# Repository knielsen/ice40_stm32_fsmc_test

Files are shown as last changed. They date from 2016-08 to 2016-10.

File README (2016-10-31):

Small test of fast communication between STM32F4 and ICE40 using the STM32 FSMC.

Pinout for the FSMC (this for plugged into the J3 slot):

  func  STM32  ICE40
  A0    PF0    R4
  A1    PF1    R3
  D0	PD14   N10
  D1	PD15   M11
  D2	PD0    T16
  NE2	PG9    N12
  NOE	PD4    T13
  NWE	PD5    P13

The external clock for the ICE40 is on J3. A test pin PB11 on the
STM32F4 is connected to R16 on the ICE40. A serial Tx out from STM32
can be connected from PB10 on the STM32F4 board to T15 on the ICE40
(will be proxied to the FTDI on the ICE40 breakout board).

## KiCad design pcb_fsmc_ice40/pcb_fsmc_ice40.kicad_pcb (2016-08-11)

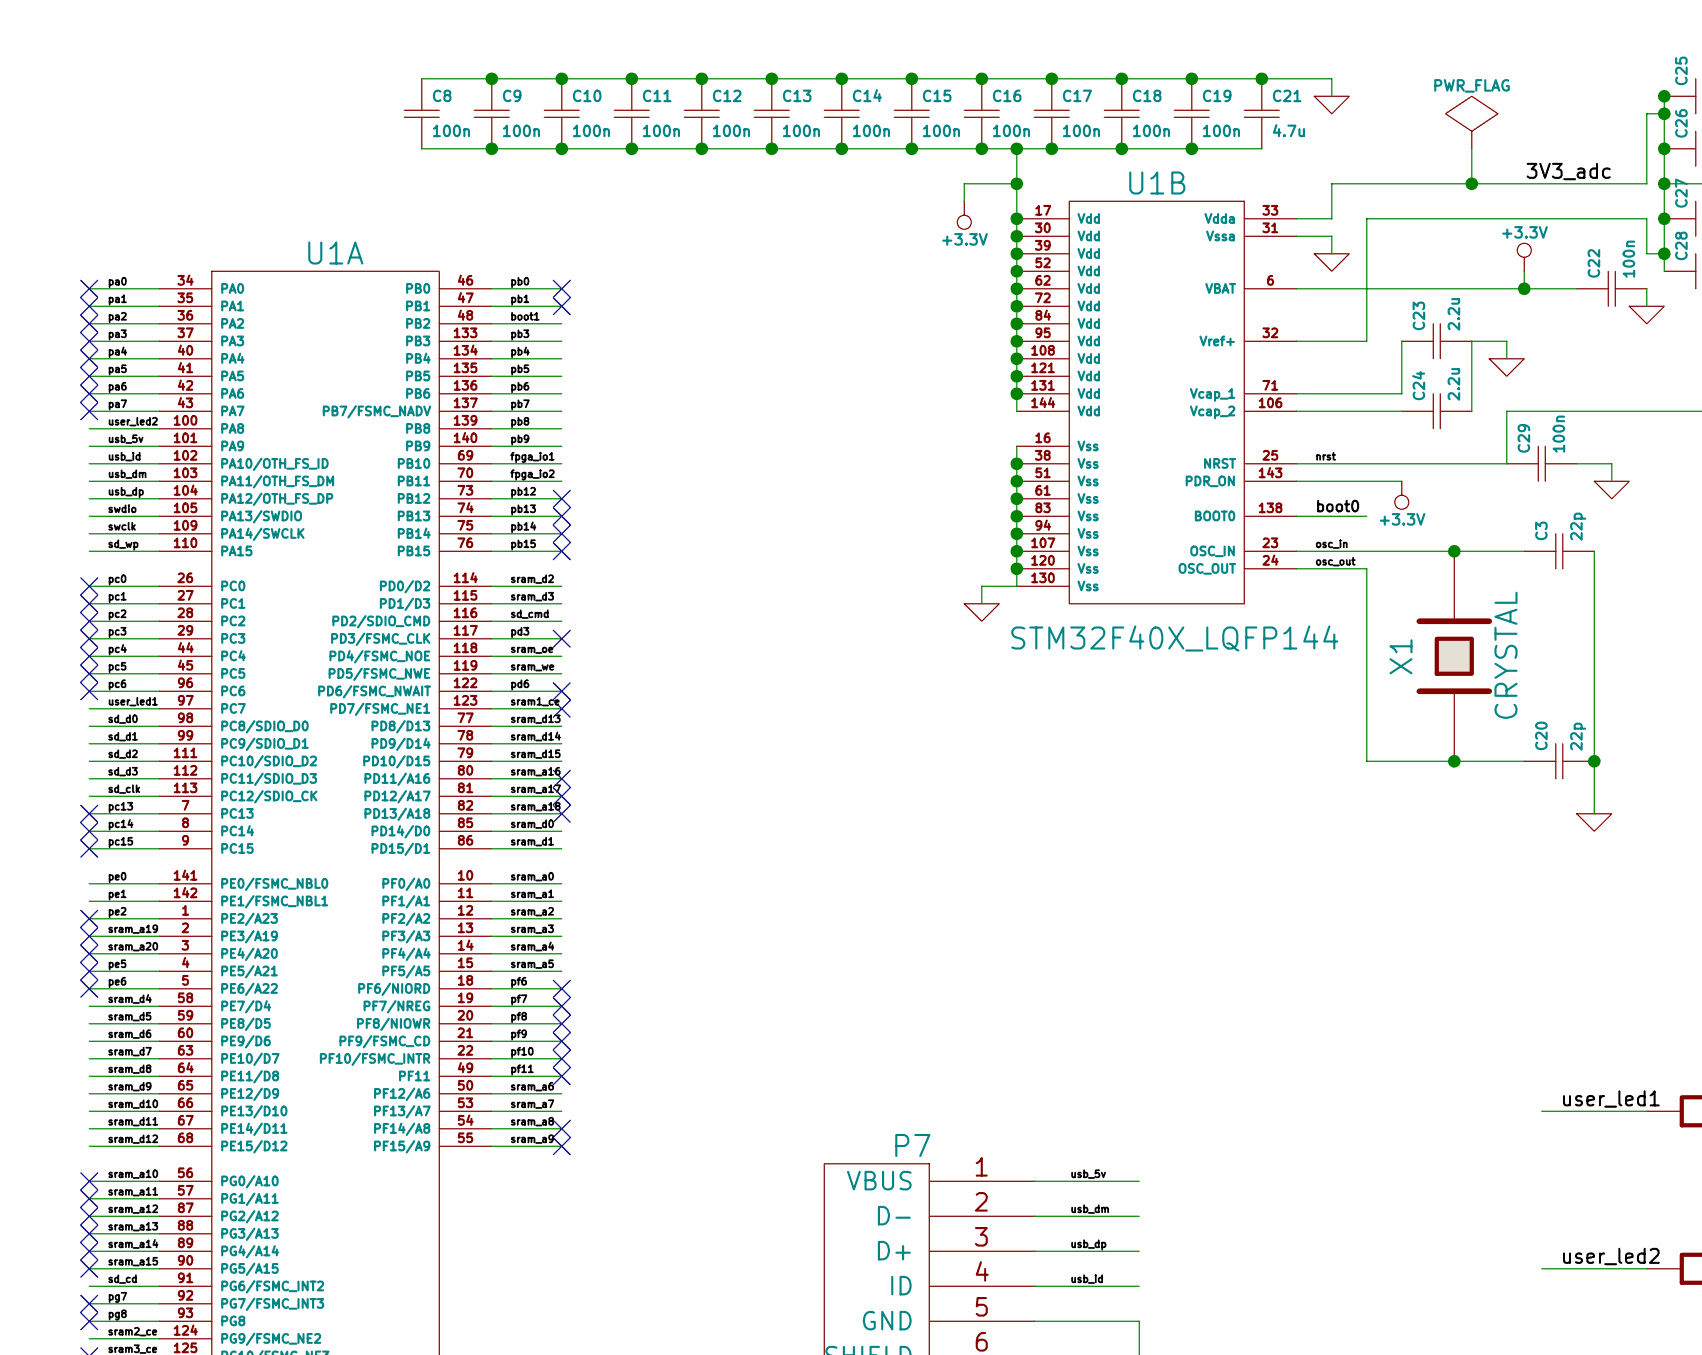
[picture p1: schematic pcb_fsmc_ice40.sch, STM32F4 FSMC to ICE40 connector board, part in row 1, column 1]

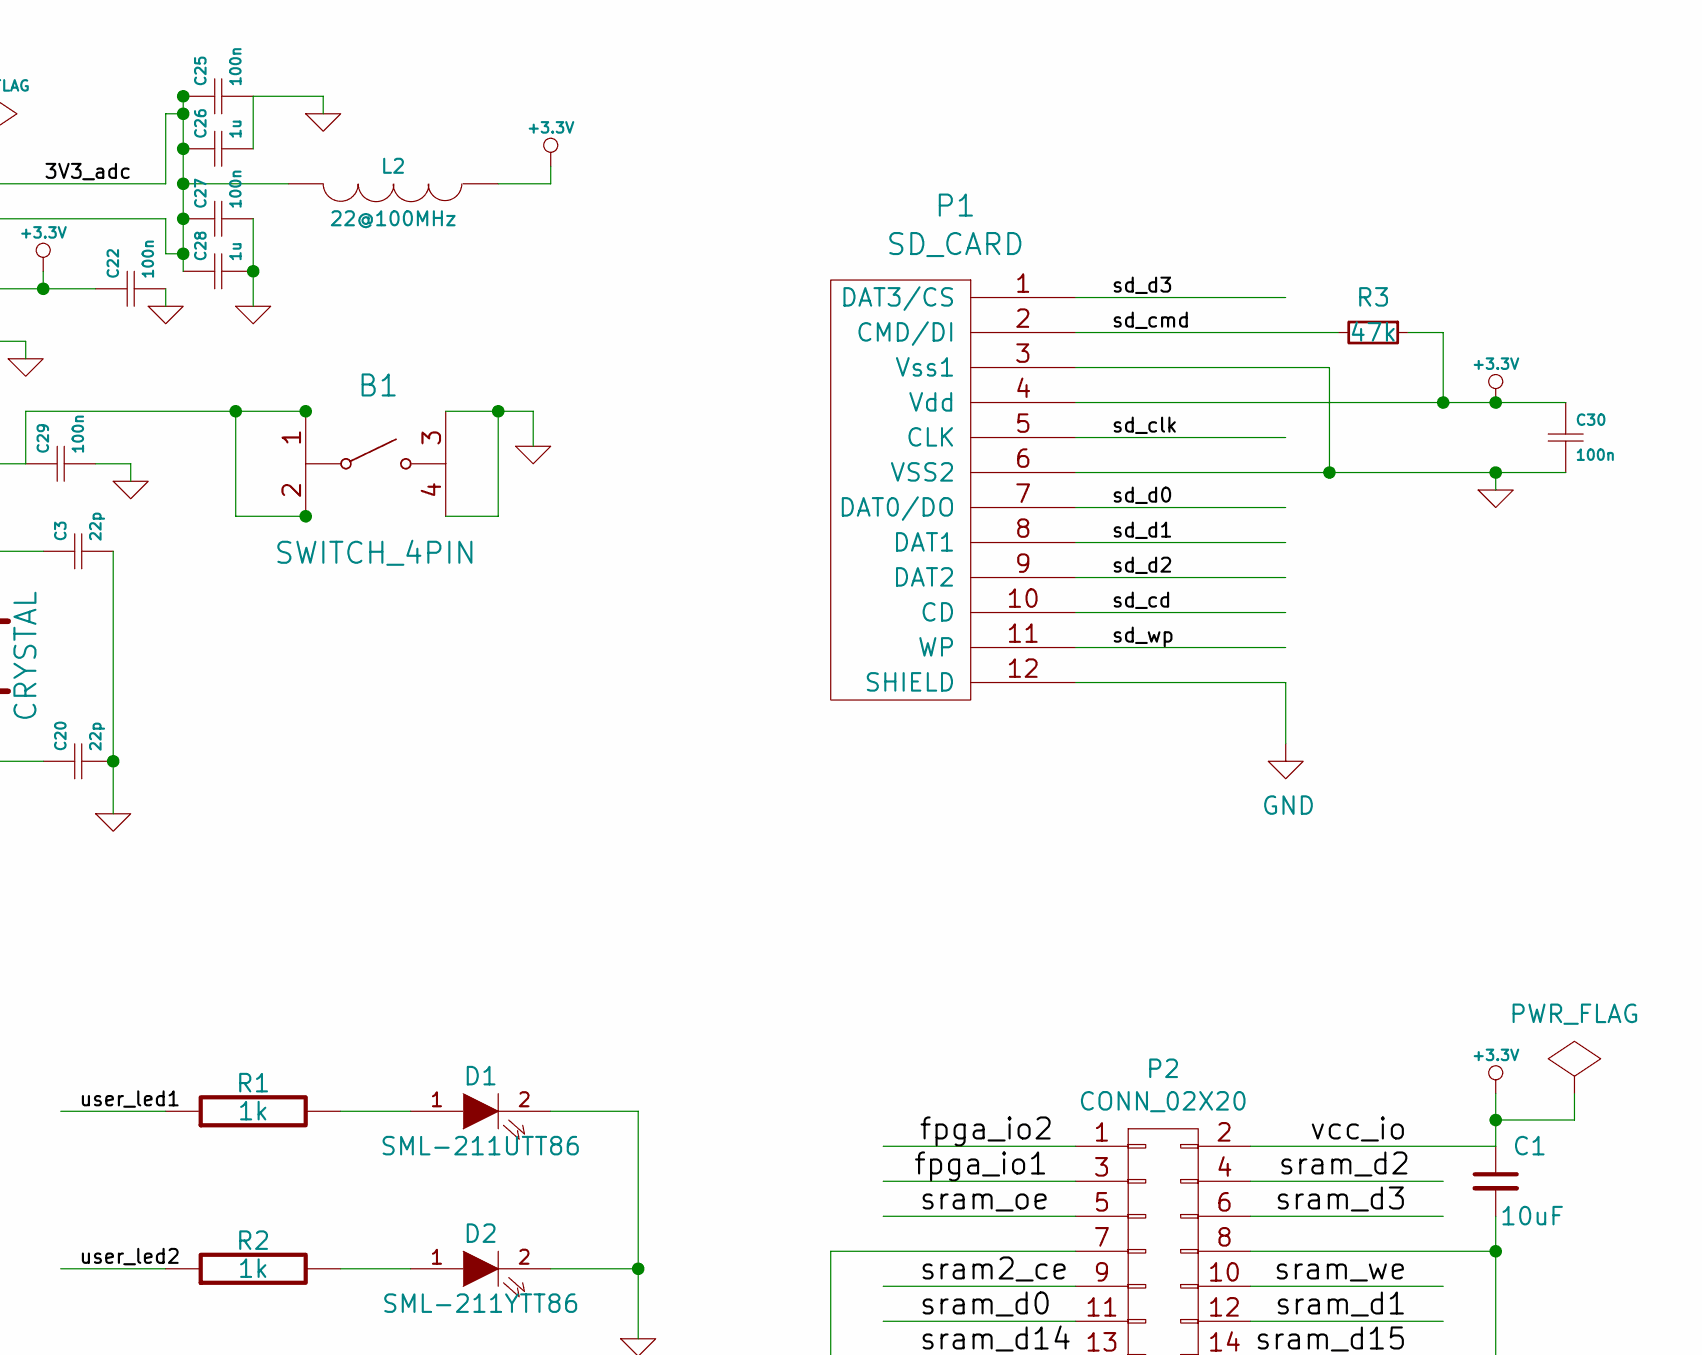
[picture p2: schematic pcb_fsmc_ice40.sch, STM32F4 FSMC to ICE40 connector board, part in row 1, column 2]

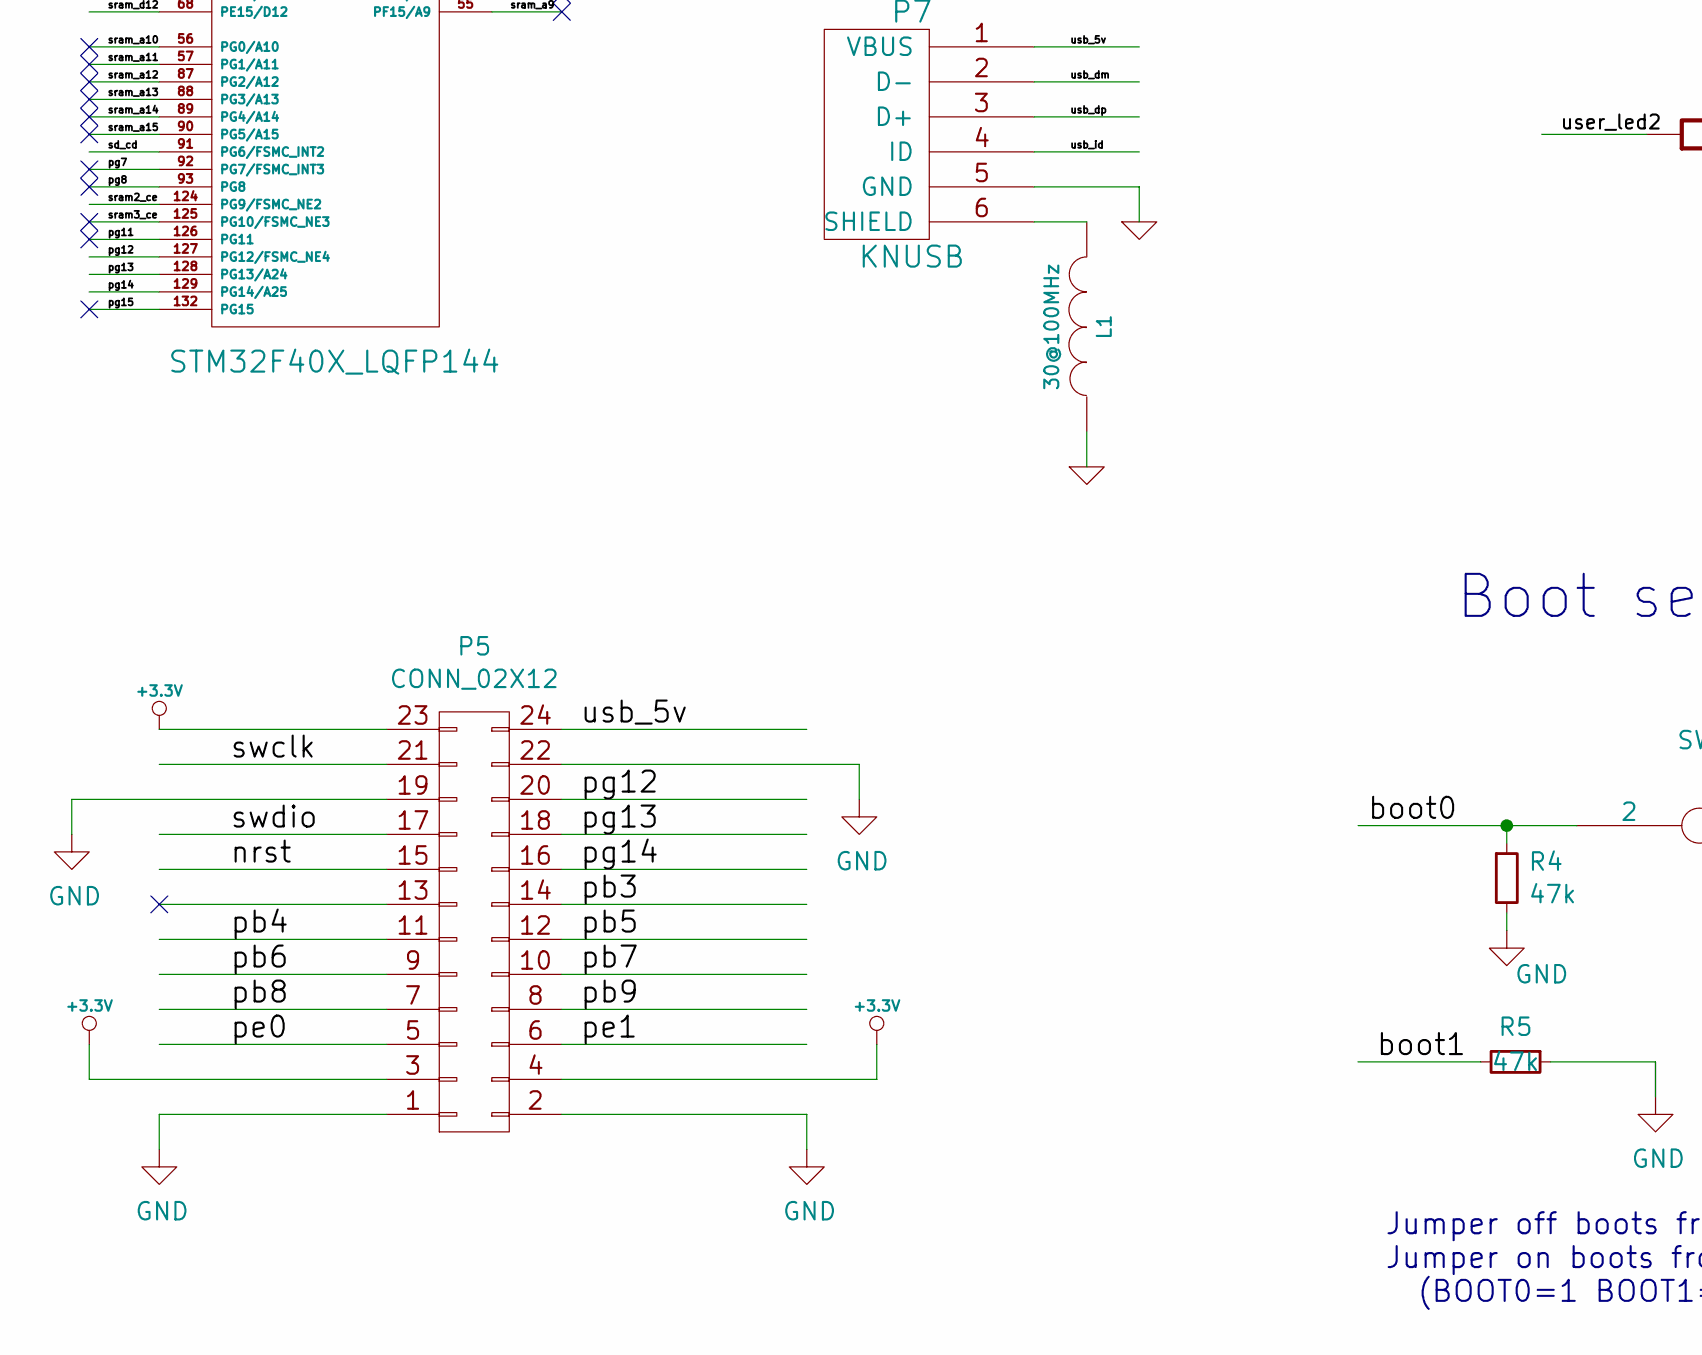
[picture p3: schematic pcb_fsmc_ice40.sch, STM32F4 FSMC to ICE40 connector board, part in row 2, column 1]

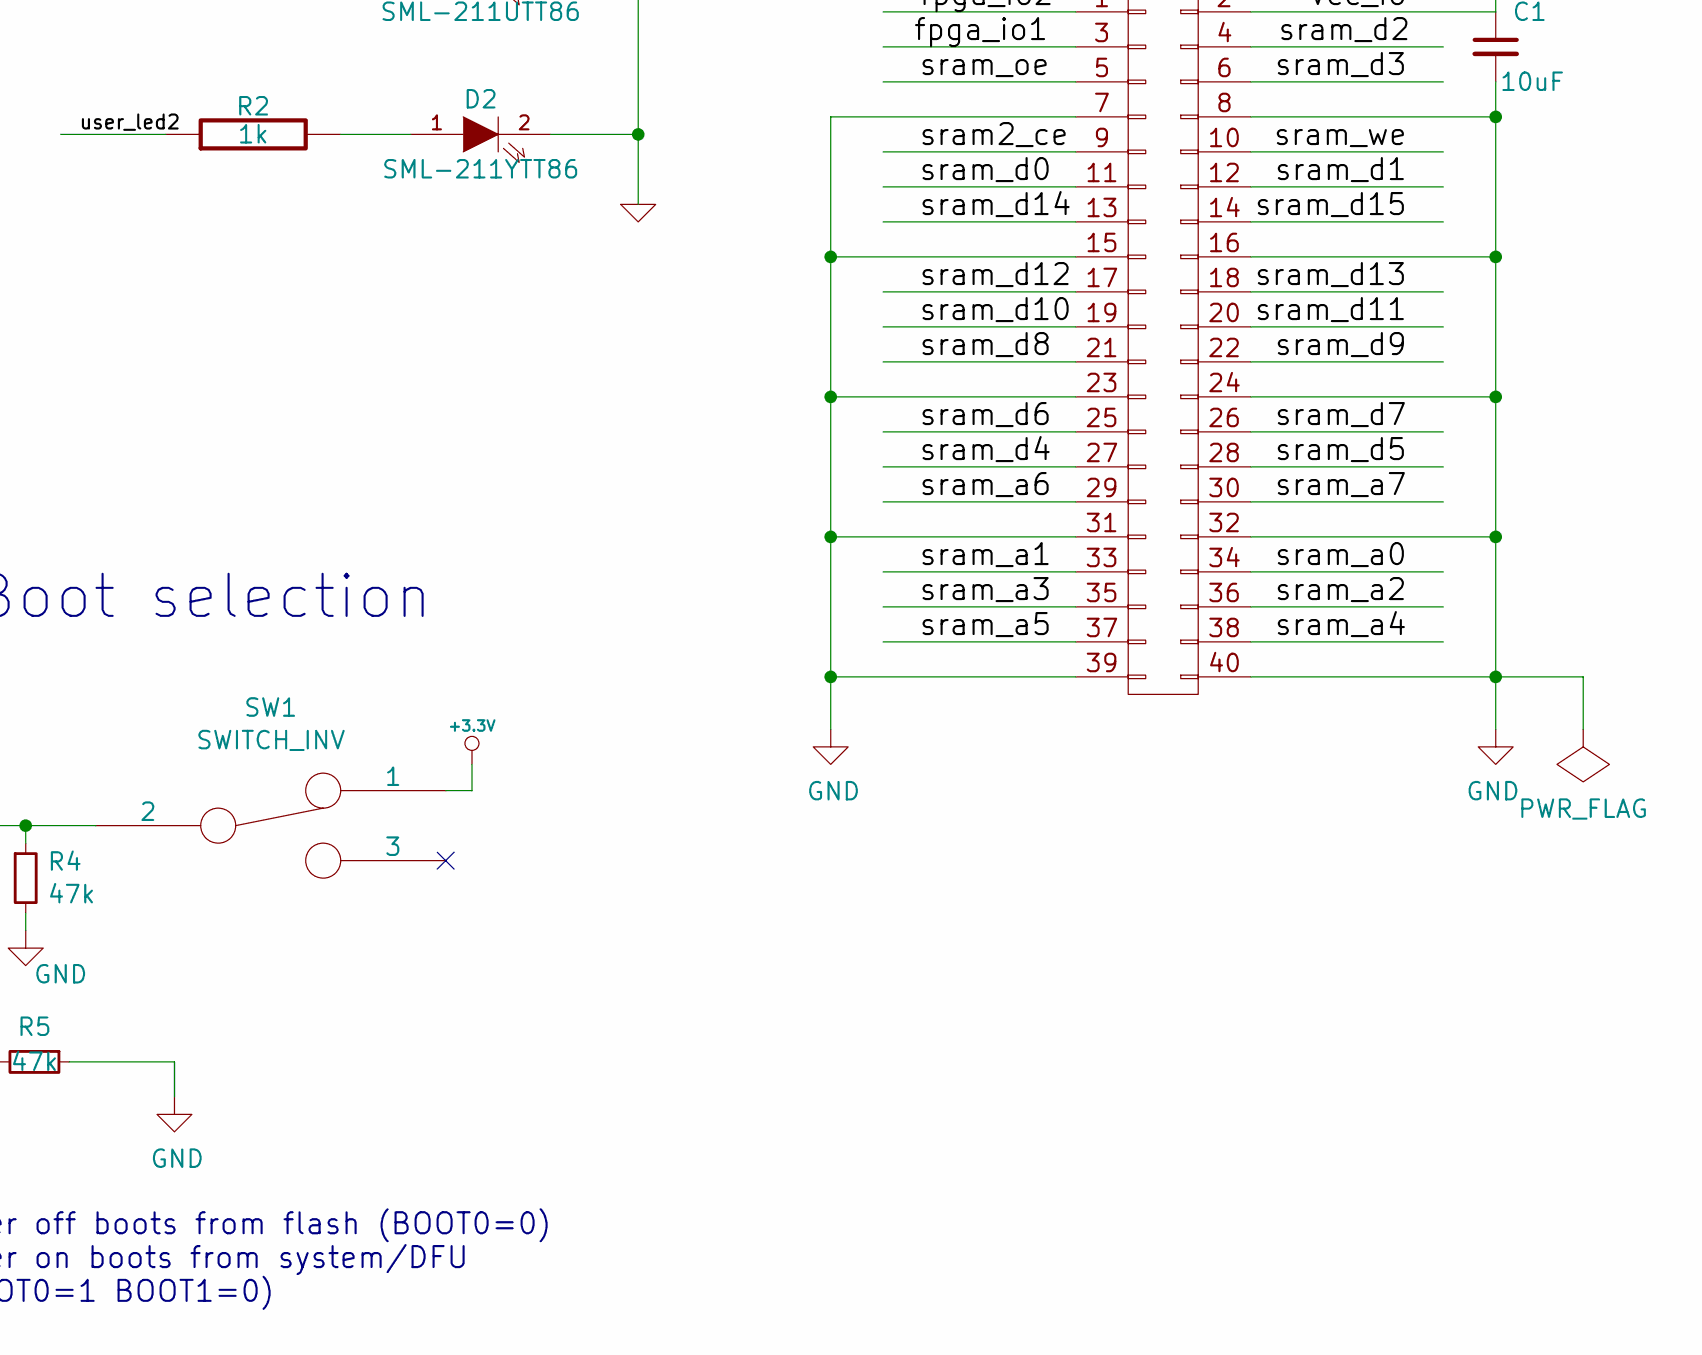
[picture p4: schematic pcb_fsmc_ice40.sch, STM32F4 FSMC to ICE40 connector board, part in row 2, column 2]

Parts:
B1: SWITCH_4PIN; pushbutton_EVQ_PSR02K
C1: 10uF; C_0805
C3, C20: 22p; C_0603
C8, C9, C10, C11, C12, C13, C14, C15, C16, C17, C18, C19, C22, C25, C27, C29, C30: 100n; C_0603
C21: 4.7u; C_0603
C23, C24: 2.2u; C_0603
C26, C28: 1u; C_0603
D1: SML-211UTT86; LED_0603
D2: SML-211YTT86; LED_0603
L1: 30@100MHz; C_0603
L2: 22@100MHz; C_0603
P1: SD_CARD; SD_CARD_10100
P2: CONN_02X20; ice40_vert_conn
P5: CONN_02X12; ice40_top_conn_12
P7: KNUSB; 10103594-0001LF
R1, R2: 1k; R_0603
R3, R4, R5: 47k; R_0603
SW1: SWITCH_INV; switch_msk_12c02
U1: STM32F40X_LQFP144; LQFP-144_20x20mm_Pitch0.5mm
X1: CRYSTAL; 2-SOJ

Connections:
+3.3V: C1.1, C8.2, C9.2, C10.2, C11.2, C12.2, C13.2, C14.2, C15.2, C16.2, C17.2, C18.2, C19.2, C21.2, C22.1, C30.1, L2.1, P1.4 (Vdd), P2.2, P5.3, P5.4, P5.23, R3.1, SW1.1, U1.6 (VBAT), U1.17 (Vdd), U1.30 (Vdd), U1.39 (Vdd), U1.52 (Vdd), U1.62 (Vdd), U1.72 (Vdd), U1.84 (Vdd), U1.95 (Vdd), U1.108 (Vdd), U1.121 (Vdd), U1.131 (Vdd), U1.143 (PDR_ON), U1.144 (Vdd)
/3V3_adc: C25.1, C26.1, C27.1, C28.1, L2.2, U1.32 (Vref+), U1.33 (Vdda)
/boot0: R4.1, SW1.2, U1.138 (BOOT0)
/boot1: R5.2, U1.48 (PB2)
/fpga_io1: P2.3, U1.69 (PB10)
/fpga_io2: P2.1, U1.70 (PB11)
/nrst: B1.1, B1.2, C29.1, P5.15, U1.25 (NRST)
/osc_in: C3.1, U1.23 (OSC_IN), X1.2
/osc_out: C20.1, U1.24 (OSC_OUT), X1.1
/pa0: U1.34 (PA0)
/pa1: U1.35 (PA1)
/pa2: U1.36 (PA2)
/pa3: U1.37 (PA3)
/pa4: U1.40 (PA4)
/pa5: U1.41 (PA5)
/pa6: U1.42 (PA6)
/pa7: U1.43 (PA7)
/pb0: U1.46 (PB0)
/pb1: U1.47 (PB1)
/pb3: P5.14, U1.133 (PB3)
/pb4: P5.11, U1.134 (PB4)
/pb5: P5.12, U1.135 (PB5)
/pb6: P5.9, U1.136 (PB6)
/pb7: P5.10, U1.137 (PB7/FSMC_NADV)
/pb8: P5.7, U1.139 (PB8)
/pb9: P5.8, U1.140 (PB9)
/pb12: U1.73 (PB12)
/pb13: U1.74 (PB13)
/pb14: U1.75 (PB14)
/pb15: U1.76 (PB15)
/pc0: U1.26 (PC0)
/pc1: U1.27 (PC1)
/pc2: U1.28 (PC2)
/pc3: U1.29 (PC3)
/pc4: U1.44 (PC4)
/pc5: U1.45 (PC5)
/pc6: U1.96 (PC6)
/pc13: U1.7 (PC13)
/pc14: U1.8 (PC14)
/pc15: U1.9 (PC15)
/pd3: U1.117 (PD3/FSMC_CLK)
/pd6: U1.122 (PD6/FSMC_NWAIT)
/pe0: P5.5, U1.141 (PE0/FSMC_NBL0)
/pe1: P5.6, U1.142 (PE1/FSMC_NBL1)
/pe2: U1.1 (PE2/A23)
/pe5: U1.4 (PE5/A21)
/pe6: U1.5 (PE6/A22)
/pf6: U1.18 (PF6/NIORD)
/pf7: U1.19 (PF7/NREG)
/pf8: U1.20 (PF8/NIOWR)
/pf9: U1.21 (PF9/FSMC_CD)
/pf10: U1.22 (PF10/FSMC_INTR)
/pf11: U1.49 (PF11)
/pg7: U1.92 (PG7/FSMC_INT3)
/pg8: U1.93 (PG8)
/pg11: U1.126 (PG11)
/pg12: P5.20, U1.127 (PG12/FSMC_NE4)
/pg13: P5.18, U1.128 (PG13/A24)
/pg14: P5.16, U1.129 (PG14/A25)
/pg15: U1.132 (PG15)
/sd_cd: P1.10 (CD), U1.91 (PG6/FSMC_INT2)
/sd_clk: P1.5 (CLK), U1.113 (PC12/SDIO_CK)
/sd_cmd: P1.2 (CMD/DI), R3.2, U1.116 (PD2/SDIO_CMD)
/sd_d0: P1.7 (DAT0/DO), U1.98 (PC8/SDIO_D0)
/sd_d1: P1.8 (DAT1), U1.99 (PC9/SDIO_D1)
/sd_d2: P1.9 (DAT2), U1.111 (PC10/SDIO_D2)
/sd_d3: P1.1 (DAT3/CS), U1.112 (PC11/SDIO_D3)
/sd_wp: P1.11 (WP), U1.110 (PA15)
/sram1_ce: U1.123 (PD7/FSMC_NE1)
/sram2_ce: P2.9, U1.124 (PG9/FSMC_NE2)
/sram3_ce: U1.125 (PG10/FSMC_NE3)
/sram_a0: P2.34, U1.10 (PF0/A0)
/sram_a1: P2.33, U1.11 (PF1/A1)
/sram_a2: P2.36, U1.12 (PF2/A2)
/sram_a3: P2.35, U1.13 (PF3/A3)
/sram_a4: P2.38, U1.14 (PF4/A4)
/sram_a5: P2.37, U1.15 (PF5/A5)
/sram_a6: P2.29, U1.50 (PF12/A6)
/sram_a7: P2.30, U1.53 (PF13/A7)
/sram_a8: U1.54 (PF14/A8)
/sram_a9: U1.55 (PF15/A9)
/sram_a10: U1.56 (PG0/A10)
/sram_a11: U1.57 (PG1/A11)
/sram_a12: U1.87 (PG2/A12)
/sram_a13: U1.88 (PG3/A13)
/sram_a14: U1.89 (PG4/A14)
/sram_a15: U1.90 (PG5/A15)
/sram_a16: U1.80 (PD11/A16)
/sram_a17: U1.81 (PD12/A17)
/sram_a18: U1.82 (PD13/A18)
/sram_a19: U1.2 (PE3/A19)
/sram_a20: U1.3 (PE4/A20)
/sram_d0: P2.11, U1.85 (PD14/D0)
/sram_d1: P2.12, U1.86 (PD15/D1)
/sram_d2: P2.4, U1.114 (PD0/D2)
/sram_d3: P2.6, U1.115 (PD1/D3)
/sram_d4: P2.27, U1.58 (PE7/D4)
/sram_d5: P2.28, U1.59 (PE8/D5)
/sram_d6: P2.25, U1.60 (PE9/D6)
/sram_d7: P2.26, U1.63 (PE10/D7)
/sram_d8: P2.21, U1.64 (PE11/D8)
/sram_d9: P2.22, U1.65 (PE12/D9)
/sram_d10: P2.19, U1.66 (PE13/D10)
/sram_d11: P2.20, U1.67 (PE14/D11)
/sram_d12: P2.17, U1.68 (PE15/D12)
/sram_d13: P2.18, U1.77 (PD8/D13)
/sram_d14: P2.13, U1.78 (PD9/D14)
/sram_d15: P2.14, U1.79 (PD10/D15)
/sram_oe: P2.5, U1.118 (PD4/FSMC_NOE)
/sram_we: P2.10, U1.119 (PD5/FSMC_NWE)
/swclk: P5.21, U1.109 (PA14/SWCLK)
/swdio: P5.17, U1.105 (PA13/SWDIO)
/usb_5v: P5.24, P7.1 (VBUS), U1.101 (PA9)
/usb_dm: P7.2 (D-), U1.103 (PA11/OTH_FS_DM)
/usb_dp: P7.3 (D+), U1.104 (PA12/OTH_FS_DP)
/usb_id: P7.4 (ID), U1.102 (PA10/OTH_FS_ID)
/user_led1: R1.1, U1.97 (PC7)
/user_led2: R2.1, U1.100 (PA8)
GND: B1.3, B1.4, C1.2, C3.2, C8.1, C9.1, C10.1, C11.1, C12.1, C13.1, C14.1, C15.1, C16.1, C17.1, C18.1, C19.1, C20.2, C21.1, C22.2, C23.2, C24.2, C25.2, C26.2, C27.2, C28.2, C29.2, C30.2, D1.2 (K), D2.2 (K), L1.1, P1.3 (Vss1), P1.6 (VSS2), P1.12 (SHIELD), P2.7, P2.8, P2.15, P2.16, P2.23, P2.24, P2.31, P2.32, P2.39, P2.40, P5.1, P5.2, P5.19, P5.22, P7.5 (GND), R4.2, R5.1, U1.16 (Vss), U1.31 (Vssa), U1.38 (Vss), U1.51 (Vss), U1.61 (Vss), U1.83 (Vss), U1.94 (Vss), U1.107 (Vss), U1.120 (Vss), U1.130 (Vss)
unnamed: C23.1, U1.71 (Vcap_1)
unnamed: C24.1, U1.106 (Vcap_2)
unnamed: D1.1 (A), R1.2
unnamed: D2.1 (A), R2.2
unnamed: L1.2, P7.6 (SHIELD)

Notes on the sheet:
Boot selection
Jumper off boots from flash (BOOT0=0) Jumper on boots from system/DFU (BOOT0=1 BOOT1=0)

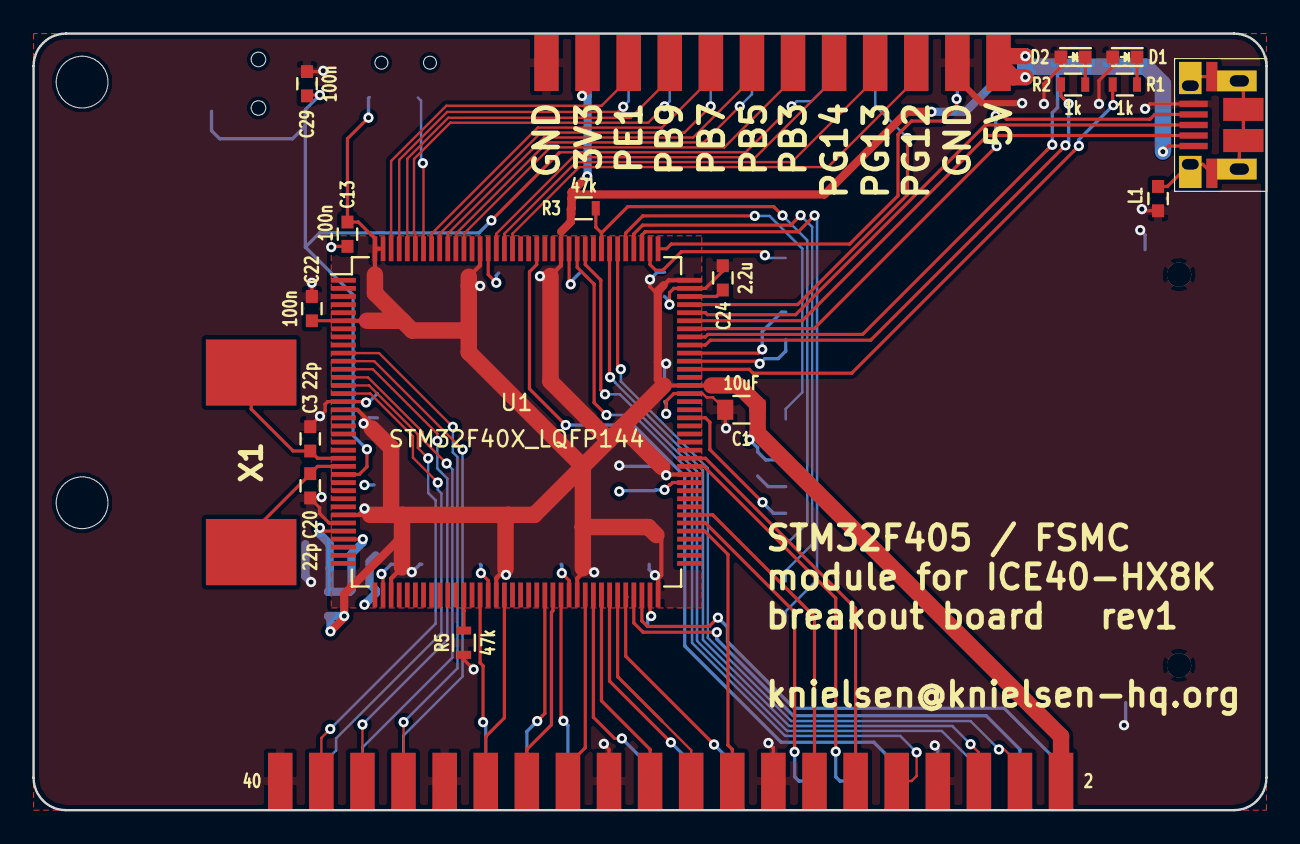
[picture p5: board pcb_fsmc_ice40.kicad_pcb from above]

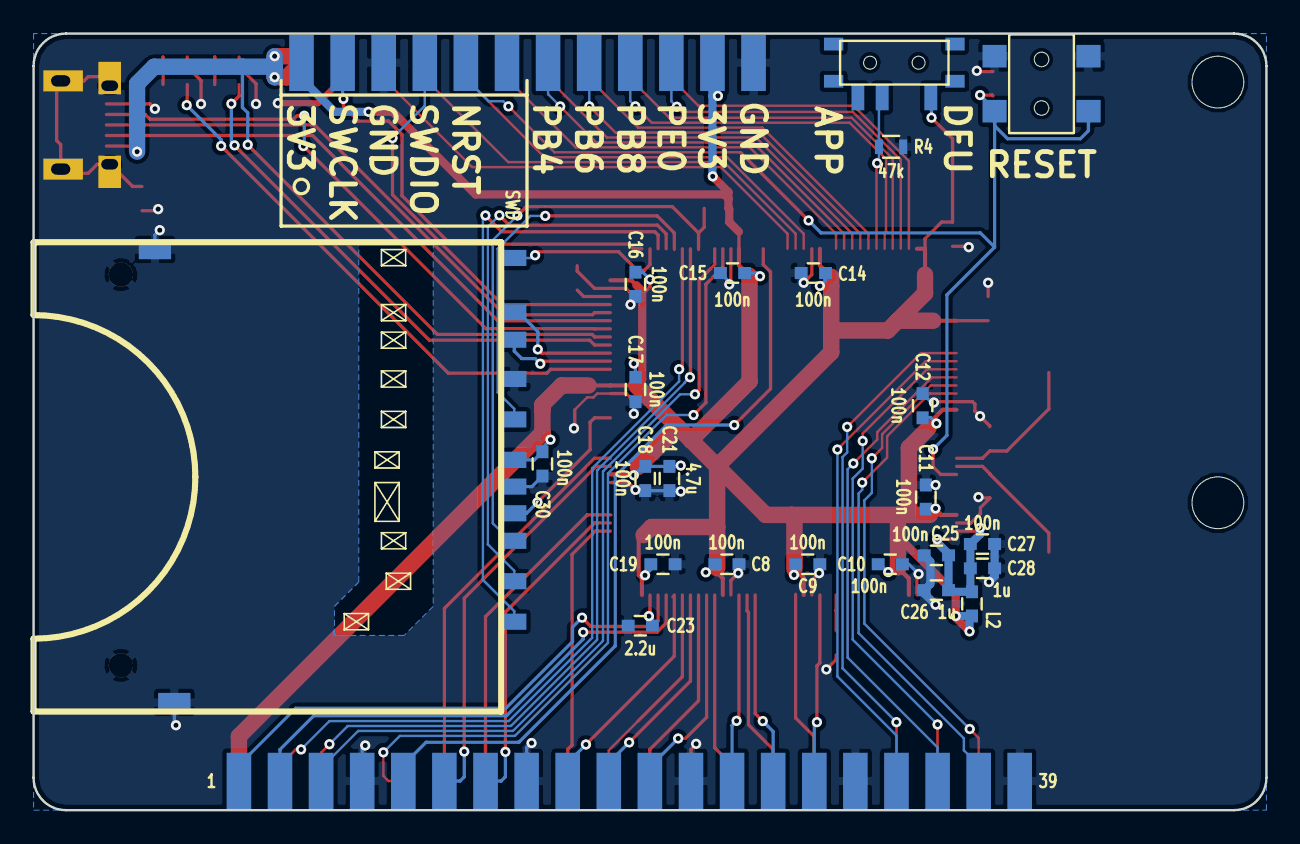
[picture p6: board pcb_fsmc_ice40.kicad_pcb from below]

Board: 2 copper layers, 76.2 x 48.0 mm, 42 parts (23 on the bottom side), 70 nets.

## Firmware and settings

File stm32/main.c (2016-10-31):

/*
 * This program turns on the 4 leds of the stm32f4 discovery board
 * one after another.
 * It defines shortcut definitions for the led pins and
 * stores the order of the leds in an array which is being
 * iterated in a loop.
 *
 * This program is free human culture like poetry, mathematics
 * and science. You may use it as such.
 */

#include <math.h>

#include <stm32f4xx.h>


#define MCU_HZ 168000000
#define SRAM_SIZE ((uint32_t)(2*1024*1024))

/* This is apparently needed for libc/libm (eg. powf()). */
int __errno;


static void delay(uint32_t nCount)
{
  /* This should be 3 cycles per iteration. nCount must be > 0. */
  __asm volatile
    ("\n"
     "0:\n\t"
     "subs %1, #1\n\t"
     "bne.n 0b"
     : "=r" (nCount)
     : "0" (nCount)
     : "cc");
}


static void setup_serial(void)
{
  GPIO_InitTypeDef GPIO_InitStructure;
  USART_InitTypeDef USART_InitStructure;

  /* enable peripheral clock for USART3 */
  RCC_APB1PeriphClockCmd(RCC_APB1Periph_USART3, ENABLE);

  /* GPIOB clock enable */
  RCC_AHB1PeriphClockCmd(RCC_AHB1Periph_GPIOB, ENABLE);

  /* GPIOB Configuration:  USART3 TX on PB10 */
  GPIO_InitStructure.GPIO_Pin = GPIO_Pin_10;
  GPIO_InitStructure.GPIO_Mode = GPIO_Mode_AF;
  GPIO_InitStructure.GPIO_Speed = GPIO_Speed_50MHz;
  GPIO_InitStructure.GPIO_OType = GPIO_OType_PP;
  GPIO_InitStructure.GPIO_PuPd = GPIO_PuPd_UP ;
  GPIO_Init(GPIOB, &GPIO_InitStructure);

  /* Connect USART3 pins to AF2 */
  // TX = PA2
  GPIO_PinAFConfig(GPIOB, GPIO_PinSource10, GPIO_AF_USART3);

  USART_InitStructure.USART_BaudRate = 115200;
  USART_InitStructure.USART_WordLength = USART_WordLength_8b;
  USART_InitStructure.USART_StopBits = USART_StopBits_1;
  USART_InitStructure.USART_Parity = USART_Parity_No;
  USART_InitStructure.USART_HardwareFlowControl = USART_HardwareFlowControl_None;
  USART_InitStructure.USART_Mode = USART_Mode_Tx;
  USART_Init(USART3, &USART_InitStructure);

  USART_Cmd(USART3, ENABLE); // enable USART3
}


#define LED_GPIO_PERIPH RCC_AHB1Periph_GPIOA
#define LED_GPIO GPIOA
#define LED_PIN GPIO_Pin_8
//#define LED_GPIO_PERIPH RCC_AHB1Periph_GPIOC
//#define LED_GPIO GPIOC
//#define LED_PIN GPIO_Pin_7

static void
setup_led(void)
{
  GPIO_InitTypeDef GPIO_InitStructure;

  RCC_AHB1PeriphClockCmd(LED_GPIO_PERIPH, ENABLE);
  GPIO_InitStructure.GPIO_Pin = LED_PIN;
  GPIO_InitStructure.GPIO_Mode  = GPIO_Mode_OUT;
  GPIO_InitStructure.GPIO_Speed = GPIO_Speed_100MHz;
  GPIO_InitStructure.GPIO_OType = GPIO_OType_PP;
  GPIO_InitStructure.GPIO_PuPd  = GPIO_PuPd_NOPULL;
  GPIO_Init(LED_GPIO, &GPIO_InitStructure);
}


static void
led_on(void)
{
  GPIO_SetBits(LED_GPIO, LED_PIN);
}


static void
led_off(void)
{
  GPIO_ResetBits(LED_GPIO, LED_PIN);
}


static void
serial_putchar(USART_TypeDef* USARTx, uint32_t c)
{
  while(!(USARTx->SR & USART_FLAG_TC));
  USART_SendData(USARTx, c);
}


static void
serial_puts(USART_TypeDef *usart, const char *s)
{
  while (*s)
    serial_putchar(usart, (uint8_t)*s++);
}


static void
serial_output_hexdig(USART_TypeDef* USARTx, uint32_t dig)
{
  serial_putchar(USARTx, (dig >= 10 ? 'A' - 10 + dig : '0' + dig));
}


__attribute__ ((unused))
static void
serial_output_hexbyte(USART_TypeDef* USARTx, uint8_t byte)
{
  serial_output_hexdig(USARTx, byte >> 4);
  serial_output_hexdig(USARTx, byte & 0xf);
}


__attribute__ ((unused))
static void
serial_output_hex(USART_TypeDef* USARTx, uint32_t v)
{
  serial_putchar(USARTx, '0');
  serial_putchar(USARTx, 'x');
  serial_output_hexbyte(USARTx, v >> 24);
  serial_output_hexbyte(USARTx, (v >> 16) & 0xff);
  serial_output_hexbyte(USARTx, (v >> 8) & 0xff);
  serial_output_hexbyte(USARTx, v & 0xff);
}


__attribute__ ((unused))
static char *
tostring_uint32(char *p, uint32_t val)
{
  uint32_t l, d;

  l = 1000000000UL;
  while (l > val && l > 1)
    l /= 10;

  do
  {
    d = val / l;
    *p++ = '0' + d;
    val -= d*l;
    l /= 10;
  } while (l > 0);
  return p;
}


static void
print_uint32(USART_TypeDef* usart, uint32_t val)
{
  char buf[13];
  char *p;

  p = tostring_uint32(buf, val);
  *p = '\0';
  serial_puts(usart, buf);
}


__attribute__ ((unused))
static void
println_uint32(USART_TypeDef* usart, uint32_t val)
{
  char buf[13];
  char *p = buf;

  p = tostring_uint32(buf, val);
  *p++ = '\r';
  *p++ = '\n';
  *p = '\0';
  serial_puts(usart, buf);
}


__attribute__ ((unused))
static void
println_int32(USART_TypeDef* usart, int32_t val)
{
  if (val < 0)
  {
    serial_putchar(usart, '-');
    println_uint32(usart, (uint32_t)0 - (uint32_t)val);
  }
  else
    println_uint32(usart, val);
}


static void
float_to_str(char *buf, float f, uint32_t dig_before, uint32_t dig_after)
{
  float a;
  uint32_t d;
  uint8_t leading_zero;

  if (f == 0.0f)
  {
    buf[0] = '0';
    buf[1] = '\0';
    return;
  }
  if (f < 0)
  {
    *buf++ = '-';
    f = -f;
  }
  a =  powf(10.0f, (float)dig_before);
  if (f >= a)
  {
    buf[0] = '#';
    buf[1] = '\0';
    return;
  }
  leading_zero = 1;
  while (dig_before)
  {
    a /= 10.0f;
    d = (uint32_t)(f / a);
    if (leading_zero && d == 0 && a >= 10.0f)
      *buf++ = ' ';
    else
    {
      leading_zero = 0;
      *buf++ = '0' + d;
      f -= d*a;
    }
    --dig_before;
  }
  if (!dig_after)
  {
    *buf++ = '\0';
    return;
  }
  *buf++ = '.';
  do
  {
    f *= 10.0f;
    d = (uint32_t)f;
    *buf++ = '0' + d;
    f -= (float)d;
    --dig_after;
  } while (dig_after);
  *buf++ = '\0';
}


__attribute__ ((unused))
static void
println_float(USART_TypeDef* usart, float f,
              uint32_t dig_before, uint32_t dig_after)
{
  char buf[21];
  char *p = buf;

  float_to_str(p, f, dig_before, dig_after);
  while (*p)
    ++p;
  *p++ = '\r';
  *p++ = '\n';
  *p = '\0';
  serial_puts(usart, buf);
}


static void
fill_mem_inc(uint16_t start, uint32_t block)
{
  uint16_t *mem = (uint16_t *)(uint32_t)0x60000000;
  uint32_t i, j;
  uint16_t v = start;

  for (i = 0; i < SRAM_SIZE; i += block)
  {
    for (j = 0; j < block; j += 2)
    {
      mem[(i+j)/2] = v;
    }
    ++v;
  }
}


static uint32_t
check_mem_inc(uint16_t start, uint32_t block)
{
  uint16_t *mem = (uint16_t *)(uint32_t)0x60000000;
  uint32_t i, j;
  uint32_t err = 0;
  uint16_t v = start;

  for (i = 0; i < SRAM_SIZE; i += block)
  {
    for (j = 0; j < block; j += 2)
    {
      uint16_t d = mem[(i+j)/2];
      if (d != v)
      {
        ++err;
        if (err <= 5)
        {
          serial_puts(USART3, "[0x");
          serial_output_hexbyte(USART3, d >> 8);
          serial_output_hexbyte(USART3, d & 0xff);
          serial_puts(USART3, "!=0x");
          serial_output_hexbyte(USART3, v >> 8);
          serial_output_hexbyte(USART3, v & 0xff);
          serial_puts(USART3, "]");
        }
      }
    }
    ++v;
  }
  return err;
}


static void
check_block(uint16_t start, uint32_t block)
{
  uint32_t err;

  serial_puts(USART3, "write block start=0x");
  serial_output_hexbyte(USART3, start >> 8);
  serial_output_hexbyte(USART3, start & 0xff);
  serial_puts(USART3, " size=");
  println_uint32(USART3, block);
  led_on();
  fill_mem_inc(start, block);

  serial_puts(USART3, "Read back ...");
  led_off();
  err = check_mem_inc(start, block);
  serial_puts(USART3, " errors=");
  println_uint32(USART3, err);
}


void
mem_test(void)
{
  uint16_t word;

  word = 1;
  while (1)
  {
    check_block(word, 2);
    check_block(word, 4);
    check_block(word, 32);
    check_block(word, 4096);
    check_block(word, 0x10000);

    word += 18637;
  }
}


__attribute__((unused))
static void
write_fpga(uint32_t offset, uint16_t val)
{
  /* 0x64000000 is the start of bank1 SRAM2. */
  volatile uint16_t *fpga = (volatile uint16_t *)(uint32_t)0x64000000;

  *(fpga+(offset>>1)) = val;
}


__attribute__((unused))
static uint16_t
read_fpga(uint32_t offset)
{
  /* 0x64000000 is the start of bank1 SRAM2. */
  volatile uint16_t *fpga = (volatile uint16_t *)(uint32_t)0x64000000;

  return *(fpga+(offset>>1));
}


__attribute__((unused))
static void
pulse_pin_test(void)
{
  GPIO_InitTypeDef GPIO_InitStructure;
  uint16_t val1, val2;

  /* GPIOF clock enable */
  RCC_AHB1PeriphClockCmd(RCC_AHB1Periph_GPIOF, ENABLE);

  /* GPIOF Configuration: Output pulse on PF11. */
  GPIO_InitStructure.GPIO_Pin = GPIO_Pin_11;
  GPIO_InitStructure.GPIO_Mode = GPIO_Mode_OUT;
  GPIO_InitStructure.GPIO_Speed = GPIO_Speed_50MHz;
  GPIO_InitStructure.GPIO_OType = GPIO_OType_PP;
  GPIO_InitStructure.GPIO_PuPd = GPIO_PuPd_NOPULL ;
  GPIO_Init(GPIOF, &GPIO_InitStructure);

  val1 = 0;
  val2 = 0;
  for (;;) {
    write_fpga(0, val1++);
    GPIO_SetBits(GPIOF, GPIO_Pin_11);
    led_on();
    delay(MCU_HZ/3/4);
    write_fpga(0, val1++);
    write_fpga(2, val2++);
    GPIO_ResetBits(GPIOF, GPIO_Pin_11);
    led_off();
    delay(MCU_HZ/3/4);
  }
}


__attribute__((unused))
static void
fpga_test(void)
{
again:
  led_on();
  write_fpga(0, 0b111);
  write_fpga(2, 0b111);
  write_fpga(4, 0b000);
  write_fpga(6, 0b000);
  serial_puts(USART3, "Read back: ");
  serial_output_hex(USART3, read_fpga(0));
  serial_puts(USART3, " ");
  serial_output_hex(USART3, read_fpga(2));
  serial_puts(USART3, " ");
  serial_output_hex(USART3, read_fpga(4));
  serial_puts(USART3, " ");
  serial_output_hex(USART3, read_fpga(6));
  serial_puts(USART3, "\n");

  delay(MCU_HZ/3);
  led_off();
  write_fpga(0, 0b000);
  write_fpga(2, 0b000);
  serial_puts(USART3, "Read back: ");
  serial_output_hex(USART3, read_fpga(0));
  serial_puts(USART3, " ");
  serial_output_hex(USART3, read_fpga(2));
  serial_puts(USART3, "\n");

  delay(MCU_HZ/3);
  led_on();
  write_fpga(0, 0b101);
  write_fpga(2, 0b010);
  serial_puts(USART3, "Read back: ");
  serial_output_hex(USART3, read_fpga(0));
  serial_puts(USART3, " ");
  serial_output_hex(USART3, read_fpga(2));
  serial_puts(USART3, "\n");

  delay(MCU_HZ/3);
  led_off();
  write_fpga(0, 0b010);
  write_fpga(2, 0b101);
  serial_puts(USART3, "Read back: ");
  serial_output_hex(USART3, read_fpga(0));
  serial_puts(USART3, " ");
  serial_output_hex(USART3, read_fpga(2));
  serial_puts(USART3, "\n");

  delay(MCU_HZ/3);
  led_on();
  write_fpga(0, 0b110);
  write_fpga(2, 0b011);
  serial_puts(USART3, "Read back: ");
  serial_output_hex(USART3, read_fpga(0));
  serial_puts(USART3, " ");
  serial_output_hex(USART3, read_fpga(2));
  serial_puts(USART3, "\n");

  delay(MCU_HZ/3);
  led_off();
  write_fpga(0, 0b111);
  write_fpga(2, 0b111);
  serial_puts(USART3, "Read back: ");
  serial_output_hex(USART3, read_fpga(0));
  serial_puts(USART3, " ");
  serial_output_hex(USART3, read_fpga(2));
  serial_puts(USART3, " ");
  serial_output_hex(USART3, read_fpga(4));
  serial_puts(USART3, " ");
  serial_output_hex(USART3, read_fpga(6));
  serial_puts(USART3, "\n");
goto again;
  for (;;)
    ;
}


__attribute__((unused))
static void
test_fsmc_reliability(void)
{
  uint16_t i0, i1, i2, i3, o0, o1, o2, o3;
  uint64_t iterations;
  uint32_t errors;
  uint32_t ledstate;

  i0 = i1 = i2 = i3 = 0;
  iterations = 0;
  errors = 0;
  ledstate = 0;
  for (;;) {
    write_fpga(12, i0);
    o0 = read_fpga(12);
    write_fpga(200, i1);
    write_fpga(120, i2);
    write_fpga(510, i3);
    o1 = read_fpga(200);
    o2 = read_fpga(120);
    o3 = read_fpga(510);

    if (errors < 10) {
      if (o0 != i0) {
        serial_puts(USART3, "Diff 0: ");
        print_uint32(USART3, i0);
        serial_puts(USART3, " != ");
        println_uint32(USART3, o0);
      }
      if (o1 != i1) {
        serial_puts(USART3, "Diff 1: ");
        print_uint32(USART3, i1);
        serial_puts(USART3, " != ");
        println_uint32(USART3, o1);
      }
      if (o2 != i2) {
        serial_puts(USART3, "Diff 2: ");
        print_uint32(USART3, i2);
        serial_puts(USART3, " != ");
        println_uint32(USART3, o2);
      }
      if (o3 != i3) {
        serial_puts(USART3, "Diff 3: ");
        print_uint32(USART3, i3);
        serial_puts(USART3, " != ");
        println_uint32(USART3, o3);
      }
    }

    errors += (o0 != i0) + (o1 != i1) + (o2 != i2) + (o3 != i3);
    i0 = (i0+1);
    i1 = (i1+3);
    i2 = (i2+6);
    i3 = (i3+7);

    ++iterations;
    if ((iterations & ((1<<22)-1)) == 0) {
      print_uint32(USART3, iterations >> 22);
      serial_puts(USART3, "  Errors: ");
      print_uint32(USART3, errors);
      serial_puts(USART3, ", pct: ");
      println_float(USART3, (float)errors/(float)iterations*(100/4), 2, 5);
      if ((ledstate = !ledstate))
        led_on();
      else
        led_off();
    }
  }
}


__attribute__((unused))
static void
test_fsmc_2(void)
{
  uint16_t i1, o1;
  uint64_t iterations;
  uint32_t errors;
  uint32_t ledstate;

  i1 = 3;
  iterations = 0;
  errors = 0;
  ledstate = 0;
  for (;;) {
    write_fpga(2, i1);
    o1 = read_fpga(2) & 0x7;

    if (errors < 10) {
      if (o1 != i1) {
        serial_puts(USART3, "Diff 1: ");
        print_uint32(USART3, i1);
        serial_puts(USART3, " != ");
        println_uint32(USART3, o1);
      }
    }

    errors += (o1 != i1);
    i1 = (i1+4) & 0x7;

    ++iterations;
    if ((iterations & ((1<<22)-1)) == 0) {
      print_uint32(USART3, iterations >> 22);
      serial_puts(USART3, "  Errors: ");
      print_uint32(USART3, errors);
      serial_puts(USART3, ", pct: ");
      println_float(USART3, (float)errors/(float)iterations*(100/4), 2, 5);
      if ((ledstate = !ledstate))
        led_on();
      else
        led_off();
    }
  }
}


__attribute__((unused))
static void
test_fsmc_3()
{
  /*
    Test write+read of all sequences S+n*I, n=0,1,2,...
    Report a matrix of whether there were errors in 10k tries, and also mark
    if there were more or less than 5 such errors.
  */
  uint32_t adr;

  for (adr = 0; adr < 8; adr += 2) {
    uint32_t S, I;

    serial_puts(USART3, "Test matrix for addr=");
    println_uint32(USART3, adr);
    serial_puts(USART3, "S  \\  I");
    for (I = 0; I < 8; ++I) {
      serial_puts(USART3, " ");
      print_uint32(USART3, I);
    }
    serial_puts(USART3, "\r\n");

    for (S = 0; S < 8; ++S) {
      print_uint32(USART3, S);
      serial_puts(USART3, "      ");
      for (I = 0; I < 8; ++I) {
        uint32_t n;
        uint32_t errors;
        uint32_t vin = S;

        errors = 0;
        for (n = 0; n < 10000; ++n) {
          uint16_t vout;
          write_fpga(adr, vin);
          vout = read_fpga(adr) & 7;
          if (vout != vin)
            ++errors;
          vin = (vin + I) & 7;
        }
        serial_puts(USART3, errors == 0 ? "  " : (errors <= 5 ? " ." : (errors <= 100 ? " ," :" *")));
      }
      serial_puts(USART3, "\r\n");
    }
  }

  for (;;);
}


__attribute__((unused))
static void
test_fsmc_4()
{
  /*
    Read-only test. ICE40 configured with counters that increase upon every
    read access.
  */

  /*
    Let's try to first read out each counter until it reaches `0'.
  */
  {
    uint32_t i;
    for (i = 0; i < 4; ++i) {
      while (read_fpga(i*2) & 0x7)
        ;
    }
  }

  for (;;) {
    serial_puts(USART3, "V0: "); println_uint32(USART3, read_fpga(0) & 0x7);
    serial_puts(USART3, " 0: "); println_uint32(USART3, read_fpga(0) & 0x7);
    serial_puts(USART3, "V1: "); println_uint32(USART3, read_fpga(2) & 0x7);
    serial_puts(USART3, "V2: "); println_uint32(USART3, read_fpga(4) & 0x7);
    serial_puts(USART3, "V3: "); println_uint32(USART3, read_fpga(6) & 0x7);

    delay(MCU_HZ/3/2);
  }
}


__attribute__((unused))
static void
test_fsmc_5()
{
  uint32_t val;

  /*
    Write-only test. ICE40 configured to check that values written are
    monotonously incrementing.
  */

  /*
    Let's try to first read out each counter until it reaches `0'.
  */
  {
    uint32_t i;
    for (i = 0; i < 4; ++i) {
      while (read_fpga(i*2) & 0x7)
        ;
    }
  }

  val = 0;
  for (;;) {
    val = (val+1) & 0x7;
    write_fpga(0, val);
    serial_puts(USART3, "V0: "); println_uint32(USART3, val);

    delay(MCU_HZ/3/10/4);
  }
}
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
int main(void)
{
  delay(2000000);
  setup_serial();
  setup_led();
  serial_puts(USART3, "Initialising...\r\n");
  delay(2000000);
  fsmc_manual_init();

  serial_puts(USART3, "Hello world, ready to blink!\r\n");

  //mem_test();
  //pulse_pin_test();
  //fpga_test();
  test_fsmc_reliability();
  //test_fsmc_2();
  //test_fsmc_3();
  //test_fsmc_4();
  //test_fsmc_5();

  return 0;
}

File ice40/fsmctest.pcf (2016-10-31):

set_io LED[0] B5
set_io LED[1] B4
set_io LED[2] A2
set_io LED[3] A1
set_io LED[4] C5
set_io LED[5] C4
set_io LED[6] B3
set_io LED[7] C3
set_io crystal_clk J3
set_io STM32_PIN R16
set_io aNE N12
set_io aNOE T13
set_io aNWE P13

set_io aA[0] R4
set_io aA[1] R3
set_io aA[2] T3
set_io aA[3] R2
set_io aA[4] T2
set_io aA[5] T1
set_io aA[6] T5
set_io aA[7] R5

set_io aD[0] N10
set_io aD[1] M11
set_io aD[2] T16
set_io aD[3] T14
set_io aD[4] T6
set_io aD[5] R6
set_io aD[6] T7
set_io aD[7] T8
set_io aD[8] T9
set_io aD[9] R9
set_io aD[10] P8
set_io aD[11] P9
set_io aD[12] T10
set_io aD[13] R10
set_io aD[14] T11
set_io aD[15] P10

set_io uart_tx_in T15
set_io uart_tx_out B12

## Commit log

2016-07-29 First step towards talking between STM32 and ICE40.
    In this commit, the STM32F4 MCU outputs a simple pulse (at around 2Hz)
    on a pin. The ICE40 reads the pin, synchronises to its own clock
    domain, detects and counts positive edges on the input, and displays
    an 8-bit counter value on the 8 LEDs on the hx8k breakout board.
2016-07-29 Enable FSMC SRAM2.
    Now we can count NE2 (chip enable) pulses on the ICE40 generated from
    writes to the FSMC on the STM32.
2016-07-29 First working (somewhat) FSMC interface between STM32 and ICE40.
    Two registers are defined, at address 0x0 and 0x2 (first and second
    16-bit word). The first bit in each address each controls a LED on the
    ICE40 board.
    Only write so far, no read.
    Doesn't work reliably. It works after flashing the STM32, but then a
    reset breaks it until next flash, somehow the NOE and NWE pins stop
    working after reset or powercycle of the STM32. Must be some wrong
    initialisation of the FSMC on the STM32-side or something. To be
    fixed...
    [fsmctest.pcf, main.c]
2016-07-30 Fix timing bug that caused STM32-side to fail after reset.
    The problem was in the STM32-generated initialisation code. It
    enables GPIOD and then immediately after configures the alternate
    functions for that GPIO. Depending on compiler internals (and
    apparently reset method), this can happen so quickly after one another
    that the GPIOD has not yet started before the access to alternate
    function config register, leaving 4 GPIOD pins not configured
    correctly for FSMC.
    Fixed by inserting some nops. However, this commit also disables using
    that startup code, instead configuring the FSMC manually from the main
    program using the SPL init functions. This also makes it clearer
    exactly what is being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
    [main.c]
2016-07-31 Partial work towards a STM32 daughterboard for ICE40 breakout board.
    [pcb_fsmc_ice40.kicad_pcb, pcb_fsmc_ice40.sch]
2016-07-31 Some more work on PCB, still work left to do.
    [pcb_fsmc_ice40.kicad_pcb, pcb_fsmc_ice40.sch]
2016-08-02 Some routing changes.
    [pcb_fsmc_ice40.kicad_pcb]
2016-08-03 Mostly complete routing.
    [pcb_fsmc_ice40.kicad_pcb, pcb_fsmc_ice40.sch]
2016-08-03 Mostly complete routing now.
    [pcb_fsmc_ice40.kicad_pcb]
2016-08-04 New implementation of FSMC interface FPGA-side.
    This is a clocked interface. It is intended to be better at avoiding
    glitches due to sync errors, for example missing the NE pulse in
    closely spaced back-to-back transactions.
    Also implements reading registers from the FPGA, this is however still
    untested...
    [main.c]
2016-08-04 Proxy a serial debug from the STM32F4 through the ICE40 to the FTDI.
    This is a nice trick for getting debug output out of the STM32F4,
    without the need for a separate usb-to-serial converter.
2016-08-04 Move the extra IO fpga_io1 and fpga_io2 to PB10/PB11.
    These have USART Rx/Tx available, so we can use these two spare IOs
    with the trick wher ethe FPGA proxies the UART signal from STM32 to
    the FTDI chip on the ICE40 board, simplifying serial debugging.
    [pcb_fsmc_ice40.kicad_pcb, pcb_fsmc_ice40.sch]
2016-08-04 Add forgotten no-connect symbol.
    [pcb_fsmc_ice40.sch]
2016-08-04 Implement 3-bit databus (tested).
    Had to decrease FSMC speed a bit more to avoid glitches. Maybe the
    nest-of-jumper-wires has influence here as well, might be a noise
    problem?
    [fsmctest.pcf, main.c]
2016-08-08 New test, read-only.
    Read out counters that increment on each read.
    Shows occasional glitches, but not yet clear exactly how...
    [main.c]
2016-08-09 Zero out registers at start of test, to better spot glitches...
    [main.c]
2016-08-11 Connect PA9 to usb_5v, as used by some ST library code.
    [pcb_fsmc_ice40.kicad_pcb, pcb_fsmc_ice40.sch]
2016-08-11 Minor tweaks.
    [pcb_fsmc_ice40.kicad_pcb, pcb_fsmc_ice40.sch]
2016-08-11 Silk screen addition.
    [pcb_fsmc_ice40.kicad_pcb]
2016-10-12 Changes to work with new plugin board for ICE40.
    Use new StdPeriph library - old HSE timeout default is too low for the
    board for some reason.
    Halt in case of HSE startup failure, for easier detection of the problem.
    Change pin mapping to work with the STM3F4 plugin board in slot J3.
    Change LED and USART pins.
    [fsmctest.pcf, main.c]
2016-10-13 Add commented-out code for second LED.
